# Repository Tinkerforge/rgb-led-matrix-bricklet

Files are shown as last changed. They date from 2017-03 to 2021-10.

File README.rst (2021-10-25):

RGB LED Matrix Bricklet
=======================

This repository contains the firmware source code and the hardware design
files. The documentation generator configs can be found at
https://github.com/Tinkerforge/generators

Repository Content
------------------

software/:
 * examples/: Examples for all supported languages
 * build/: Compiled files
 * src/: Source code of firmware
 * Makefile: Makefile to build project

hardware/:
 * Contains KiCad project files and additionally schematics as PDF

datasheets/:
 * Contains datasheets for sensors and complex ICs that are used

Hardware
--------

The hardware is designed with the open source EDA Suite KiCad
(http://www.kicad.org). Before you are able to open the files,
you have to install the Tinkerforge kicad-libraries
(https://github.com/Tinkerforge/kicad-libraries). You can either clone
them directly in hardware/ or clone them in a separate folder and
symlink them into hardware/
(ln -s kicad_path/kicad-libraries project_path/hardware). After that you
can open the .pro file in hardware/ with KiCad and from there view and
modify the schematics and the PCB layout.

Software
--------

If you want to do your own Brick/Bricklet firmware development we highly
recommend that you use our build environment setup script and read the
tutorial (https://www.tinkerforge.com/en/doc/Tutorials/Tutorial_Build_Environment/Tutorial.html).

To compile the C code we recommend you to install the newest GNU Arm Embedded
Toolchain (https://launchpad.net/gcc-arm-embedded/+download).
You also need to install bricklib2 (https://github.com/Tinkerforge/bricklib2).

You can either clone it directly in software/src/ or clone it in a
separate folder and symlink it into software/src/
(ln -s bricklib_path/bricklib2 project_path/software/src/). Finally make sure to
have CMake installed (http://www.cmake.org/cmake/resources/software.html).

After that you can build the firmware by invoking make in software/.
The firmware (.zbin) can then be found in software/build/ and uploaded
with brickv (click button "Flashing" on start screen).

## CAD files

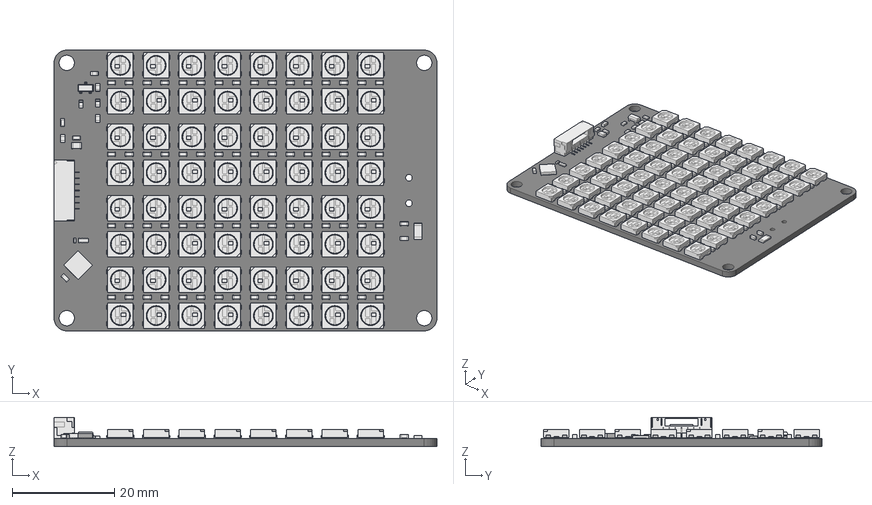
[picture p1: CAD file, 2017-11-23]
hardware/rgb-led-matrix.FCStd
75.0 x 55.0 x 5.70 mm
Pcb
QFN-24_4x4mm_Pitch0.5mm_
BrickletConn_7pin_
SOT23_
C_0603_
C_0603_001
C_0805_
C_0603_002
C_0603_003
C_0603_004
C_0603_005
C_0603_006
C_0603_007
C_0603_008
C_0603_009
C_0603_010
C_0603_011
C_0603_012
C_0603_013
C_0603_014
C_0603_015
C_0603_016
C_0603_017
C_0603_018
C_0603_019
C_0603_020
C_0603_021
C_0603_022
C_0603_023
C_0603_024
C_0603_025
C_0603_026
C_0603_027
C_0603_028
C_0603_029
C_0603_030
C_0603_031
C_0603_032
C_0603_033
C_0603_034
C_0603_035
C_0603_036
C_0603_037
C_0603_038
C_0603_039
C_0603_040
C_0603_041
C_0603_042
C_0603_043
C_0603_044
C_0603_045
C_0603_046
C_0603_047
C_0603_048
C_0603_049
C_0603_050
C_0603_051
C_0603_052
C_0603_053
C_0603_054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

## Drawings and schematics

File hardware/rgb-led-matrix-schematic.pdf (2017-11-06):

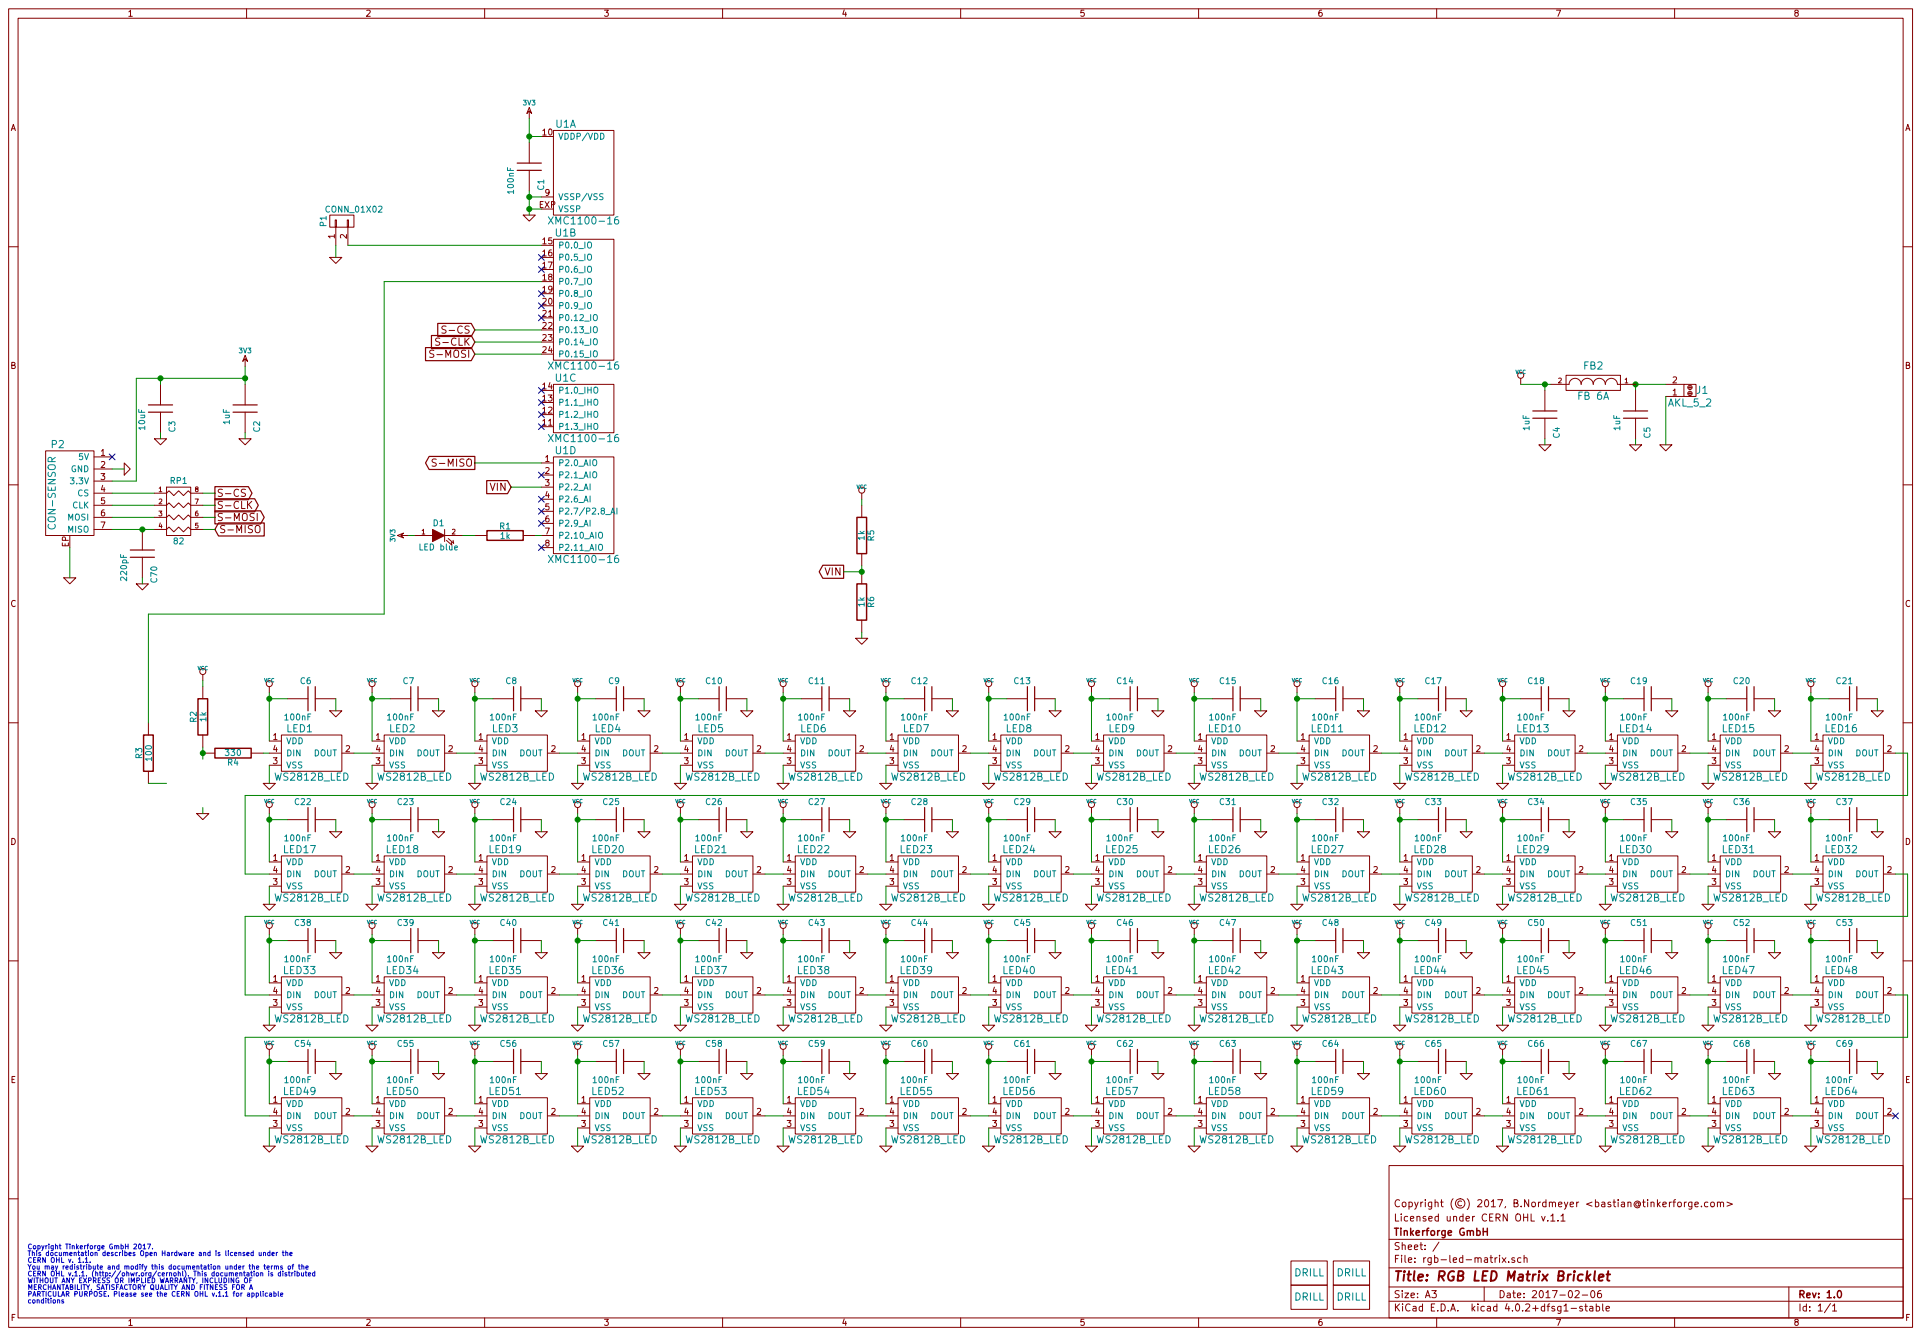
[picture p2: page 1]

Licensed under CERN OHL v.1.1 Copyright (©) 2017, B.Nordmeyer <bastian@tinkerforge.com>

File: rgb-led-matrix.sch Sheet: / Tinkerforge GmbH

Copyright Tinkerforge GmbH 2017. This documentation describes Open Hardware and is licensed under the CERN OHL v. 1.1. You may redistribute and modify this documentation under the terms of the CERN OHL v.1.1. (http://ohwr.org/cernohl). This documentation is distributed WITHOUT ANY EXPRESS OR IMPLIED WARRANTY, INCLUDING OF MERCHANTABILITY, SATISFACTORY QUALITY AND FITNESS FOR A

Id: 1/1 Title: RGB LED Matrix Bricklet

PARTICULAR PURPOSE. Please see the CERN OHL v.1.1 for applicable

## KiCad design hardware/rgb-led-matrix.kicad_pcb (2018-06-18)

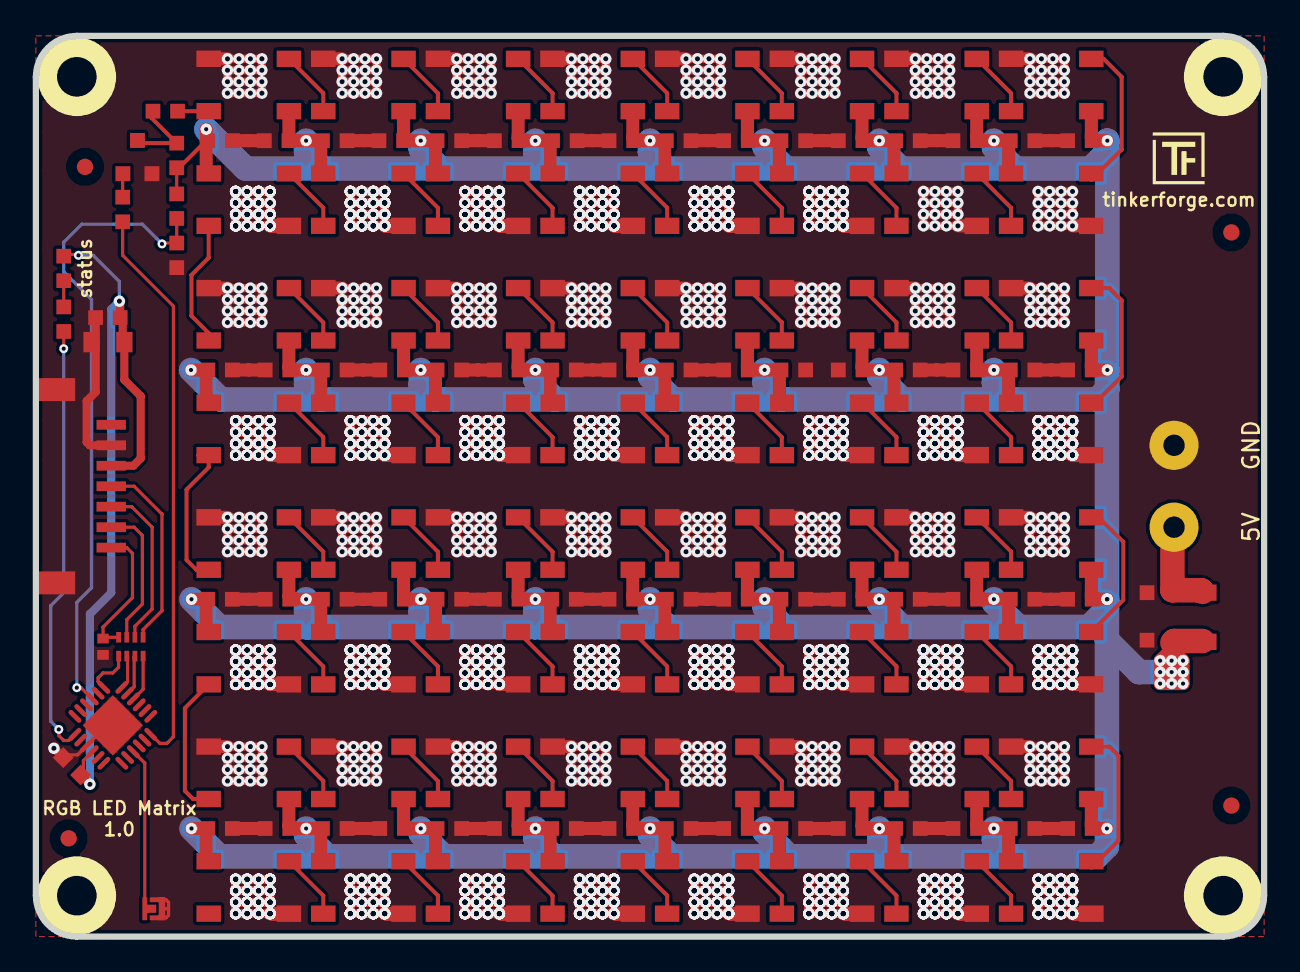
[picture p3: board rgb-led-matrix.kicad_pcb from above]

Board: 2 copper layers, 75.0 x 55.0 mm, 157 parts (0 on the bottom side), 82 nets.

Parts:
C1, C6, C7, C8, C9, C10, C11, C12, C13, C14, C15, C16, C17, C18, C19, C20, C21, C22, C23, C24, C25, C26, C27, C28, C29, C30, C31, C32, C33, C34, C35, C36, C37, C38, C39, C40, C41, C42, C43, C44, C45, C46, C47, C48, C49, C50, C51, C52, C53, C54, C55, C56, C57, C58, C59, C60, C61, C62, C63, C64, C65, C66, C67, C68, C69: 100nF; C0603F
C2, C4, C5: 1uF; C0603F
C3: 10uF; C0805
C70: 220pF; C0402F
D1: LED blue; D0603F
FB2: FB 6A; R1206
Fiducial_Mark: VAL**; Fiducial_Mark
Fiducial_Mark#2, Fiducial_Mark#3, Fiducial_Mark#4: VAL**; Fiducial_Mark
J1: AKL_5_2
LED1, LED2, LED3, LED4, LED5, LED6, LED7, LED8, LED9, LED10, LED11, LED12, LED13, LED14, LED15, LED16, LED17, LED18, LED19, LED20, LED21, LED22, LED23, LED24, LED25, LED26, LED27, LED28, LED29, LED30, LED31, LED32, LED33, LED34, LED35, LED36, LED37, LED38, LED39, LED40, LED41, LED42, LED43, LED44, LED45, LED46, LED47, LED48, LED49, LED50, LED51, LED52, LED53, LED54, LED55, LED56, LED57, LED58, LED59, LED60, LED61, LED62, LED63, LED64: WS2812B_LED
P1: CONN_01X02; SolderJumper
P2: CON-SENSOR; CON-SENSOR2
Q1: 2N7002P; SOT23GDS
R1, R2, R5, R6: 1k; R0603F
R3: 100; R0603F
R4: 330; R0603F
RP1: 82; 4X0402
U1: XMC1100-16; QFN24-4x4mm-0.5mm
U2, U3, U4, U5: DRILL; DRILL_NP
VAL: CE_5mm

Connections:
3V3: C1.2, C2.2, C3.2, D1.1, P2.3, U1.10
GND: C1.1, C2.1, C3.1, C4.1, C5.1, C6.2, C7.2, C8.2, C9.2, C10.2, C11.2, C12.2, C13.2, C14.2, C15.2, C16.2, C17.2, C18.2, C19.2, C20.2, C21.2, C22.2, C23.2, C24.2, C25.2, C26.2, C27.2, C28.2, C29.2, C30.2, C31.2, C32.2, C33.2, C34.2, C35.2, C36.2, C37.2, C38.2, C39.2, C40.2, C41.2, C42.2, C43.2, C44.2, C45.2, C46.2, C47.2, C48.2, C49.2, C50.2, C51.2, C52.2, C53.2, C54.2, C55.2, C56.2, C57.2, C58.2, C59.2, C60.2, C61.2, C62.2, C63.2, C64.2, C65.2, C66.2, C67.2, C68.2, C69.2, C70.1, J1.1, LED1.3, LED2.3, LED3.3, LED4.3, LED5.3, LED6.3, LED7.3, LED8.3, LED9.3, LED10.3, LED11.3, LED12.3, LED13.3, LED14.3, LED15.3, LED16.3, LED17.3, LED18.3, LED19.3, LED20.3, LED21.3, LED22.3, LED23.3, LED24.3, LED25.3, LED26.3, LED27.3, LED28.3, LED29.3, LED30.3, LED31.3, LED32.3, LED33.3, LED34.3, LED35.3, LED36.3, LED37.3, LED38.3, LED39.3, LED40.3, LED41.3, LED42.3, LED43.3, LED44.3, LED45.3, LED46.3, LED47.3, LED48.3, LED49.3, LED50.3, LED51.3, LED52.3, LED53.3, LED54.3, LED55.3, LED56.3, LED57.3, LED58.3, LED59.3, LED60.3, LED61.3, LED62.3, LED63.3, LED64.3, P1.1, P2.2, P2.EP, Q1.S, R6.2, U1.9, U1.EXP
unnamed: C5.2, FB2.1, J1.2
unnamed: C70.2, P2.7, RP1.4
unnamed: D1.2, R1.1
unnamed: LED1.2, LED2.4
unnamed: LED1.4, R4.1
unnamed: LED2.2, LED3.4
unnamed: LED3.2, LED4.4
unnamed: LED4.2, LED5.4
unnamed: LED5.2, LED6.4
unnamed: LED6.2, LED7.4
unnamed: LED7.2, LED8.4
unnamed: LED8.2, LED9.4
unnamed: LED10.2, LED11.4
unnamed: LED9.2, LED10.4
unnamed: LED11.2, LED12.4
unnamed: LED12.2, LED13.4
unnamed: LED13.2, LED14.4
unnamed: LED14.2, LED15.4
unnamed: LED15.2, LED16.4
unnamed: LED16.2, LED17.4
unnamed: LED17.2, LED18.4
unnamed: LED18.2, LED19.4
unnamed: LED19.2, LED20.4
unnamed: LED20.2, LED21.4
unnamed: LED21.2, LED22.4
unnamed: LED22.2, LED23.4
unnamed: LED23.2, LED24.4
unnamed: LED24.2, LED25.4
unnamed: LED25.2, LED26.4
unnamed: LED26.2, LED27.4
unnamed: LED27.2, LED28.4
unnamed: LED28.2, LED29.4
unnamed: LED29.2, LED30.4
unnamed: LED30.2, LED31.4
unnamed: LED31.2, LED32.4
unnamed: LED32.2, LED33.4
unnamed: LED33.2, LED34.4
unnamed: LED34.2, LED35.4
unnamed: LED35.2, LED36.4
unnamed: LED36.2, LED37.4
unnamed: LED37.2, LED38.4
unnamed: LED38.2, LED39.4
unnamed: LED39.2, LED40.4
unnamed: LED40.2, LED41.4
unnamed: LED41.2, LED42.4
unnamed: LED42.2, LED43.4
unnamed: LED43.2, LED44.4
unnamed: LED44.2, LED45.4
unnamed: LED45.2, LED46.4
unnamed: LED46.2, LED47.4
unnamed: LED47.2, LED48.4
unnamed: LED48.2, LED49.4
unnamed: LED49.2, LED50.4
unnamed: LED50.2, LED51.4
unnamed: LED51.2, LED52.4
unnamed: LED52.2, LED53.4
unnamed: LED53.2, LED54.4
unnamed: LED54.2, LED55.4
unnamed: LED55.2, LED56.4
unnamed: LED56.2, LED57.4
unnamed: LED57.2, LED58.4
unnamed: LED58.2, LED59.4
unnamed: LED59.2, LED60.4
unnamed: LED60.2, LED61.4
unnamed: LED61.2, LED62.4
unnamed: LED62.2, LED63.4
unnamed: LED63.2, LED64.4
unnamed: P1.2, U1.15
unnamed: P2.4, RP1.1
unnamed: P2.5, RP1.2
unnamed: P2.6, RP1.3
unnamed: R1.2, U1.7
unnamed: R2.1, R4.2
unnamed: R3.2, U1.18
S-CLK: RP1.7, U1.23
S-CS: RP1.8, U1.22
S-MISO: RP1.5, U1.1
S-MOSI: RP1.6, U1.24
VCC: C4.2, C6.1, C7.1, C8.1, C9.1, C10.1, C11.1, C12.1, C13.1, C14.1, C15.1, C16.1, C17.1, C18.1, C19.1, C20.1, C21.1, C22.1, C23.1, C24.1, C25.1, C26.1, C27.1, C28.1, C29.1, C30.1, C31.1, C32.1, C33.1, C34.1, C35.1, C36.1, C37.1, C38.1, C39.1, C40.1, C41.1, C42.1, C43.1, C44.1, C45.1, C46.1, C47.1, C48.1, C49.1, C50.1, C51.1, C52.1, C53.1, C54.1, C55.1, C56.1, C57.1, C58.1, C59.1, C60.1, C61.1, C62.1, C63.1, C64.1, C65.1, C66.1, C67.1, C68.1, C69.1, FB2.2, LED1.1, LED2.1, LED3.1, LED4.1, LED5.1, LED6.1, LED7.1, LED8.1, LED9.1, LED10.1, LED11.1, LED12.1, LED13.1, LED14.1, LED15.1, LED16.1, LED17.1, LED18.1, LED19.1, LED20.1, LED21.1, LED22.1, LED23.1, LED24.1, LED25.1, LED26.1, LED27.1, LED28.1, LED29.1, LED30.1, LED31.1, LED32.1, LED33.1, LED34.1, LED35.1, LED36.1, LED37.1, LED38.1, LED39.1, LED40.1, LED41.1, LED42.1, LED43.1, LED44.1, LED45.1, LED46.1, LED47.1, LED48.1, LED49.1, LED50.1, LED51.1, LED52.1, LED53.1, LED54.1, LED55.1, LED56.1, LED57.1, LED58.1, LED59.1, LED60.1, LED61.1, LED62.1, LED63.1, LED64.1, R2.2, R5.1
VIN: R5.2, R6.1, U1.3

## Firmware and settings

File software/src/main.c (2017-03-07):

/* rgb-led-matrix-bricklet
 * Copyright (C) 2017 Olaf Lüke <olaf@tinkerforge.com>
 *
 * main.c: Initialization for RGB LED Matrix Bricklet
 *
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
 * You should have received a copy of the GNU Lesser General Public
 * License along with this library; if not, write to the
 * Free Software Foundation, Inc., 59 Temple Place - Suite 330,
 * Boston, MA 02111-1307, USA.
 */

#include <stdio.h>
#include <stdbool.h>

#include "configs/config.h"

#include "bricklib2/bootloader/bootloader.h"
#include "bricklib2/hal/system_timer/system_timer.h"
#include "bricklib2/utility/communication_callback.h"
#include "communication.h"
#include "matrix.h"

Matrix matrix;

int main(void) {
	communication_callback_init();
	matrix_init(&matrix);

	while(true) {
		bootloader_tick();
		matrix_tick(&matrix);
		communication_tick();
	}

}

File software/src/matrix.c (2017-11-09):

/* rgb-led-matrix-bricklet
 * Copyright (C) 2017 Olaf Lüke <olaf@tinkerforge.com>
 *
 * matrix.c: WS2812B 8x8 Matrix driver
 *
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
 * You should have received a copy of the GNU Lesser General Public
 * License along with this library; if not, write to the
 * Free Software Foundation, Inc., 59 Temple Place - Suite 330,
 * Boston, MA 02111-1307, USA.
 */

#include "matrix.h"

#include "xmc_spi.h"
#include "xmc_gpio.h"
#include "xmc_vadc.h"

#include "configs/config_matrix.h"
#include "configs/config.h"

#include "bricklib2/hal/system_timer/system_timer.h"

#include <string.h>

#define MATRIX_SPI_FREQUENCY 3200000
#define MATRIX_HIGH_PATTERN 0b1110
#define MATRIX_LOW_PATTERN  0b1000

#define matrix_tx_irq_handler IRQ_Hdlr_12

extern Matrix matrix;

// Use global pointer to be used more efficiently in IRQ handler
// Using matrix.* in IRQ handler was about 2x slower!
const uint16_t *matrix_buffer_pointer_end = matrix.buffer_out + MATRIX_STUFFED_SIZE-1;
uint16_t *matrix_buffer_pointer = matrix.buffer_out + MATRIX_STUFFED_SIZE;

void __attribute__((optimize("-O3"))) __attribute__ ((section (".ram_code"))) matrix_tx_irq_handler(void) {
	while(!(MATRIX_USIC->TRBSR & USIC_CH_TRBSR_TFULL_Msk)) {
		MATRIX_USIC->IN[0] = *matrix_buffer_pointer++;
	}

	// We always run until the buffer is full, we may overrun the actual number of LEDs,
	// but the actual buffer is many bytes bigger and the last bytes in the array are
	// always 0. So the additional zeroes at the end do nothing.
	if(matrix_buffer_pointer > matrix_buffer_pointer_end) {
		XMC_USIC_CH_TXFIFO_DisableEvent(MATRIX_USIC, XMC_USIC_CH_TXFIFO_EVENT_CONF_STANDARD);
	}
}

void matrix_draw_frame(Matrix *matrix) {
	// Only allow draw frame if last frame is already done
	if(matrix_buffer_pointer <= matrix_buffer_pointer_end) {
		return;
	}

	matrix->frame_started = true;
	matrix->frame_last_time = system_timer_get_ms();

	matrix->buffer_out[0] = 0;

	uint32_t buffer_out_counter = 0;
	for(uint32_t i = 0; i < MATRIX_SIZE; i++) {
		uint32_t pos = i;
		if(i/8 & 1) {
			uint8_t line = i/8;
			uint8_t line_pos = i - line*8;
			pos = line*8 + (7-line_pos);
		}
		for(uint32_t j = 0; j < MATRIX_CHANNELS; j++) {
			uint8_t byte = 0;
			switch(j) {
				case 0: byte = matrix->buffer_in.g[pos]; break;
				case 1: byte = matrix->buffer_in.r[pos]; break;
				case 2: byte = matrix->buffer_in.b[pos]; break;
			}

			for(int32_t k = 7; k >= 0 ; k--) {
				uint8_t pattern = (byte & (1 << k)) ? MATRIX_HIGH_PATTERN : MATRIX_LOW_PATTERN;
				uint8_t last_two_bit_value = k & 0b11;
				matrix->buffer_out[buffer_out_counter] |= (pattern << (MATRIX_STUFFED_BITS_PER_BIT*last_two_bit_value));
				if(last_two_bit_value == 0b00) {
					buffer_out_counter++;
					matrix->buffer_out[buffer_out_counter] = 0;
				}
			}
		}
	}

	matrix_buffer_pointer = &matrix->buffer_out[0];
	matrix->frame_current_index = 0;
	XMC_USIC_CH_TXFIFO_EnableEvent(MATRIX_USIC, XMC_USIC_CH_TXFIFO_EVENT_CONF_STANDARD);
	XMC_USIC_CH_TriggerServiceRequest(MATRIX_USIC, MATRIX_SERVICE_REQUEST_TX);
}

void matrix_measure_voltage(Matrix *matrix) {
	static uint32_t last_time = 0;
	if(system_timer_is_time_elapsed_ms(last_time, 250)) {
		last_time = system_timer_get_ms();
		uint32_t result = XMC_VADC_GLOBAL_GetDetailedResult(VADC);
		if(result & (1 << 31)) {
			// Resistor divisor is 1k to 1k so we have to go from 0-4095 to 0-3.3V with a multiplier of (1+1)/1 = 2
			matrix->voltage = (result & 0xFFFF)*3300*2/4095;
		}
	}
}

void matrix_init_adc(Matrix *matrix) {
	// This structure contains the Global related Configuration.
	const XMC_VADC_GLOBAL_CONFIG_t adc_global_config = {
		.boundary0 = (uint32_t) 0, // Lower boundary value for Normal comparison mode
		.boundary1 = (uint32_t) 0, // Upper boundary value for Normal comparison mode

		.class0 = {
			.sample_time_std_conv     = 31,                      // The Sample time is (2*tadci)
			.conversion_mode_standard = XMC_VADC_CONVMODE_12BIT, // 12bit conversion Selected

		},
		.class1 = {
			.sample_time_std_conv     = 31,                      // The Sample time is (2*tadci)
			.conversion_mode_standard = XMC_VADC_CONVMODE_12BIT, // 12bit conversion Selected

		},

		.data_reduction_control         = 0, // Data Reduction disabled
		.wait_for_read_mode             = 0, // GLOBRES Register will not be overwritten until the previous value is read
		.event_gen_enable               = 0, // Result Event from GLOBRES is disabled
		.disable_sleep_mode_control     = 0  // Sleep mode is enabled
	};


	// Global iclass0 configuration
	const XMC_VADC_GLOBAL_CLASS_t adc_global_iclass_config = {
		.conversion_mode_standard = XMC_VADC_CONVMODE_12BIT,
		.sample_time_std_conv	  = 31,
	};

	// Global Result Register configuration structure
	XMC_VADC_RESULT_CONFIG_t adc_global_result_config = {
		.data_reduction_control = 0, // No Accumulation
		.post_processing_mode   = XMC_VADC_DMM_REDUCTION_MODE,
		.wait_for_read_mode  	= 1, // Enabled
		.part_of_fifo       	= 0, // No FIFO
		.event_gen_enable   	= 0  // Disable Result event
	};

	// LLD Background Scan Init Structure
	const XMC_VADC_BACKGROUND_CONFIG_t adc_background_config = {
		.conv_start_mode   = XMC_VADC_STARTMODE_CIR,       // Conversion start mode selected as cancel inject repeat
		.req_src_priority  = XMC_VADC_GROUP_RS_PRIORITY_1, // Priority of the Background request source in the VADC module
		.trigger_signal    = XMC_VADC_REQ_TR_A,            // If Trigger needed then this denotes the Trigger signal
		.trigger_edge      = XMC_VADC_TRIGGER_EDGE_NONE,   // If Trigger needed then this denotes Trigger edge selected
		.gate_signal       = XMC_VADC_REQ_GT_A,			   // If Gating needed then this denotes the Gating signal
		.timer_mode        = 0,							   // Timer Mode Disabled
		.external_trigger  = 0,                            // Trigger is Disabled
		.req_src_interrupt = 0,                            // Background Request source interrupt Disabled
		.enable_auto_scan  = 1,
		.load_mode         = XMC_VADC_SCAN_LOAD_OVERWRITE
	};


	XMC_VADC_GLOBAL_Init(VADC, &adc_global_config);
	XMC_VADC_GLOBAL_StartupCalibration(VADC);

	// Initialize the Global Conversion class 0
	XMC_VADC_GLOBAL_InputClassInit(VADC, adc_global_iclass_config, XMC_VADC_GROUP_CONV_STD, 0);
	// Initialize the Global Conversion class 1
	XMC_VADC_GLOBAL_InputClassInit(VADC, adc_global_iclass_config, XMC_VADC_GROUP_CONV_STD, 1);

	// Initialize the Background Scan hardware
	XMC_VADC_GLOBAL_BackgroundInit(VADC, &adc_background_config);

	// Initialize the global result register
	XMC_VADC_GLOBAL_ResultInit(VADC, &adc_global_result_config);

	XMC_VADC_GLOBAL_BackgroundAddChannelToSequence(VADC, 0, MATRIX_ADC_CHANNEL);
	XMC_VADC_GLOBAL_SetResultEventInterruptNode(VADC, XMC_VADC_SR_SHARED_SR0);

	XMC_VADC_GLOBAL_BackgroundTriggerConversion(VADC);
}
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

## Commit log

2015-11-18 hardware files copied from rgb led bricklet
    [rgb-led-matrix.kicad_pcb, rgb-led-matrix.sch]
2015-11-18 leds not fully placed and routed
    [rgb-led-matrix.kicad_pcb, rgb-led-matrix.sch]
2015-11-23 fully routed
    [rgb-led-matrix.kicad_pcb, rgb-led-matrix.sch]
2015-12-30 todo add voltage measurement
    [rgb-led-matrix.sch]
2017-02-06 Add auto-generated firmware stub
    [cmake_config_custom.txt]
2017-02-06 Add stub for matrix driver
2017-02-06 Add matrix driver config
2017-02-06 Implement SPI communication and byte stuffing (untested)
2017-02-06 Use 6.4MHz SPI frequency
2017-02-07 add xmc1100 microcontroller
    [rgb-led-matrix.kicad_pcb, rgb-led-matrix.sch]
2017-02-07 add vias for better cooling
    [rgb-led-matrix.kicad_pcb]
2017-02-08 add fiducials and logos
    [rgb-led-matrix.kicad_pcb]
2017-02-08 remove old text
    [rgb-led-matrix.kicad_pcb, rgb-led-matrix.sch]
2017-03-07 Set correct pins, versions and sizes
    [config_custom_bootloader.h, config_custom_bootstrapper.h, config_matrix.h]
2017-03-07 Add voltage measurement support
2017-03-07 Use correct polarity and timing for SPI
    [matrix.c]
2017-03-07 Add voltage input channel define
2017-03-07 Increase adc sample time to maximum
2017-03-09 Use GRB as correct color sequence for WS2812B
    [matrix.c]
2017-03-09 Use full 32 byte buffer and trigger interrupt if 4 bytes have been used
2017-03-09 Increase interrupt speed by using pointer instead of indexes, incrementing frame number later on and putting buffer end check at end of loop
2017-03-13 Use 16 bits per word to save 50% time during interrupt
2017-05-08 fix spi filtering
    [rgb-led-matrix.kicad_pcb, rgb-led-matrix.sch]
2017-05-12 Fix CE logo
    [rgb-led-matrix.kicad_pcb]
2017-05-18 fix led connection
    [rgb-led-matrix.kicad_pcb, rgb-led-matrix.sch]
2017-05-18 adapt led pin accoring to hardware
2017-05-18 define ferrite
    [rgb-led-matrix.kicad_pcb, rgb-led-matrix.sch]
2017-06-09 Put interrupt in ram for faster function call
2017-06-09 make sure element 0 is initialized correctly
    [matrix.c]
2017-08-01 Add 3d information (fam)
    [rgb-led-matrix.kicad_pcb, rgb-led-matrix.sch]
2017-08-01 Add 3d model (*.step & *.FCStd)
    [rgb-led-matrix.FCStd]
2017-08-11 specify filter circuit
    [rgb-led-matrix.kicad_pcb, rgb-led-matrix.sch]
2017-09-08 add status led description text
    [rgb-led-matrix.kicad_pcb]
2017-09-19 specify processor
    [rgb-led-matrix.kicad_pcb, rgb-led-matrix.sch]
2017-11-06 Add final schematic
2017-11-09 Make sure draf frame function (with frame duration = 0) works properly
2017-11-23 Remove power connector
    [rgb-led-matrix.FCStd, rgb-led-matrix.kicad_pcb]
2018-02-20 Cleanup KiCad libraries config
    Ensure LibDir=kicad-libraries and LibName1=tinkerforge.
    Remove special library.
2018-06-18 Change capacitor footprint(s) to C0402F
    [rgb-led-matrix.kicad_pcb, rgb-led-matrix.sch]
2019-02-04 repair schematic
    [rgb-led-matrix.sch]
2021-10-25 Update KiCad link
    https://www.kicad.org/blog/2021/10/Avoid-links-to-former-kicad-domain/
